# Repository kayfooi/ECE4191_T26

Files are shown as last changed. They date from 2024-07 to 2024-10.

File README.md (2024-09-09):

# ECE4191_T26

### World Coordinate System

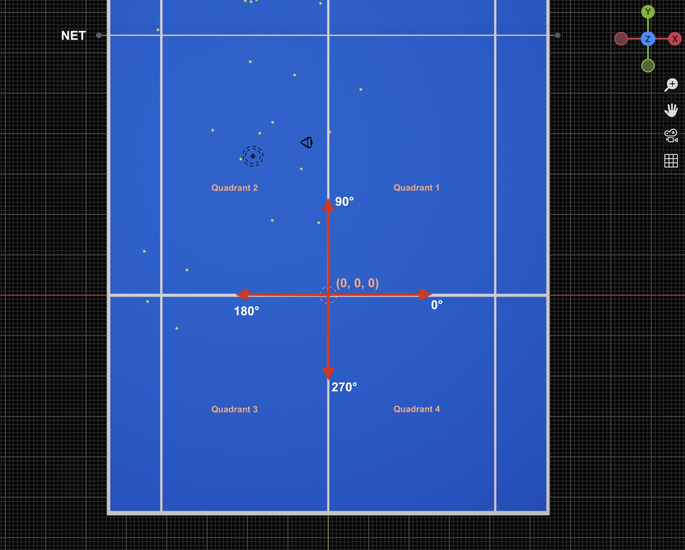
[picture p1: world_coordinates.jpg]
world coordinates


### Libraries
#### pigpio
- needs to be started, terminal command: 
```
sudo pigpiod
```
- python library that handles GPIO on a low-level
- Can produce hardware-timed PWM signals on any GPIO
- Known issue: encoder counts pause rarely and have to restart pigpio in terminal
```
sudo killall pigpiod
sudo pigpiod
```

#### ultralytics
- Loads YOLO model
- Seems quite slow so may be worth investigating other options

### Code Overview

#### [main](main.py)
High level main file to handle ALL logic relevant to the final competion

#### [camera](camera.py)
Object to handle all things computer vision including camera settings/capturing, detection algorithms and coordinate transforms

#### [robot](robot.py)
Object that implements instructions given to the robot (note that all *competition logic* should be kept in main)

#### [world](world.py)
Object that represents current state of the world. Includes tennis court dimensions, starting poses, tennnis balls etc.

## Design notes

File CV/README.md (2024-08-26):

## COMPUTER VISION NOTES

#### Calibration
- [camera_calibrate.py](camera_calibrate.py) calculates a homography matrix that transforms image coordinates into real-world coordinates (relative to a camera positioned at (0, 0, 0))
  - takes [calibration_img.png](calibration_img.png) and [calibration.csv](calibration.csv) as input
  - plots a lot of stuff
  - [calibration.csv](calibration.csv) is currently created manually (we should only need to do this a single time once the robot is constructed and the camera is in a fixed position relative to the ground)

#### Distortion
- Minor barrel distortion appears present
- No major effect on homography accuracy, especially for pixels in the centre of the image
- Attempted to use [checkerboard](./checkerboard/) images to [correct distortion with OpenCV](https://learnopencv.com/camera-calibration-using-opencv/) with minimal success

#### Object Identification
- Will probably use a combination of colour masking, edge detection, maybe k-means clustering?

#### Test case generation
- Blender used to generate many images to test the performance of various CV algorithms 
- Simulates barrel distortion from camera
- Various lighting / shadow conditions
- Various amouts of noise / motion blur

#### Testing
- Put all images in a test set in a single folder
- If you want to automatically test accuracy, create a cases.json file with the structure:
- [
    {
      "caseID": str,
      "cam_heading": int,
      "cam_location": [x,y,z],
      "balls": [{
          "ball_id": str,
          "world": [x,y,z],
          "image": [u,v],
          "in_bounds": bool
      }]
    }
  ]
- *^^ [image_labeller.py](test_imgs/image_labeller.py) can do this for you*
- Import ball detections algorithms in [test_cv.py](test_cv.py)
- Run test_cv (make sure you are in CV folder)

#### TODO
- [x] Geometry
- [ ] Tennis ball identification
- [x] Test case generation

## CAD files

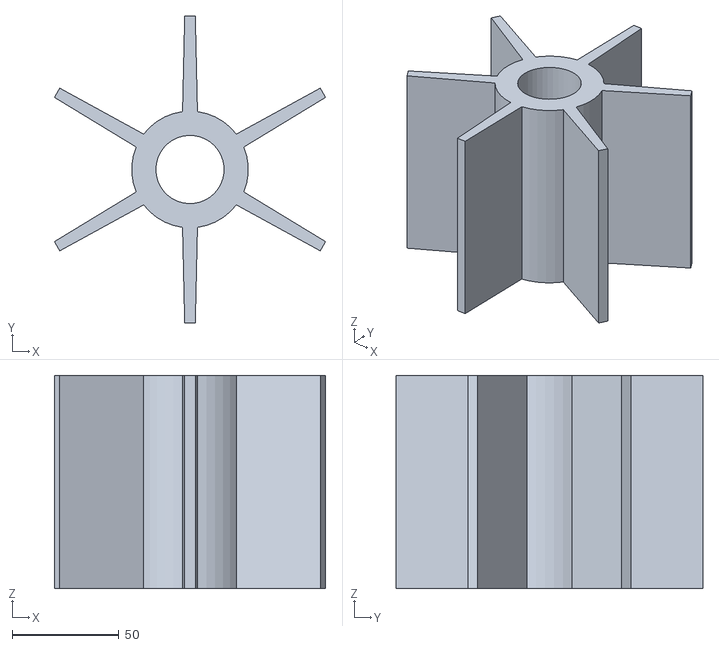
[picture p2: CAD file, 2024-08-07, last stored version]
Initial SW Paddle Designs/6SpokeDesignBigHoleEdition.STL
127.2 x 144.0 x 100.0

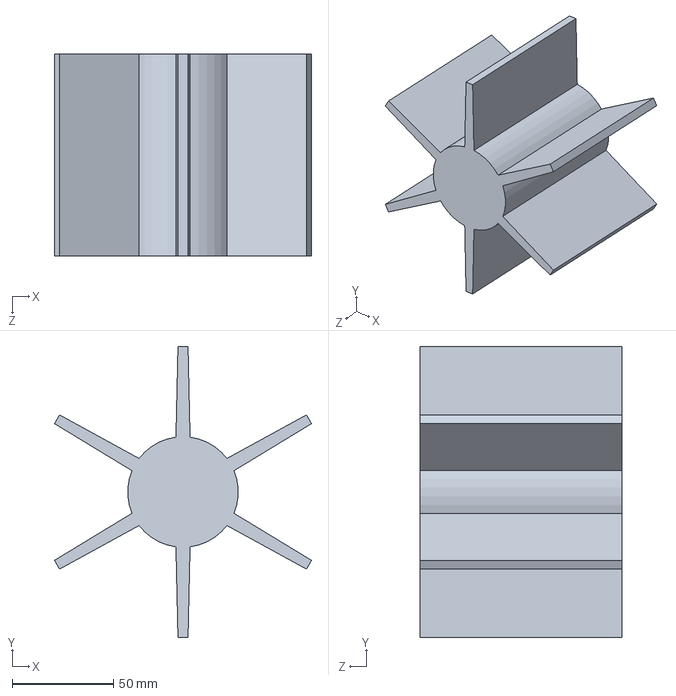
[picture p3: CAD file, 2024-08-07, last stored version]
Initial SW Paddle Designs/6SpokeDesign.SLDPRT
127.2 x 144.0 x 100.0 mm

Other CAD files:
Initial SW Paddle Designs/6SpokeDesign.STL

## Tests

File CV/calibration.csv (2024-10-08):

Image X (px) | Image Y (px) | World X (m) | World Y (m)
83 | 273 | 0.6 | 0.3
56 | 137 | 1.2 | 0.6
136 | 85 | 1.8 | 0.6
177 | 59 | 2.4 | 0.6
315 | 32 | 3.6 | 0
455 | 62 | 2.4 | -0.6
497 | 91 | 1.8 | -0.6
577 | 142 | 1.2 | -0.6
551 | 278 | 0.6 | -0.3
321 | 274 | 0.6 | 0
317 | 139 | 1.2 | 0
316 | 88 | 1.8 | 0
316 | 62 | 2.4 | 0

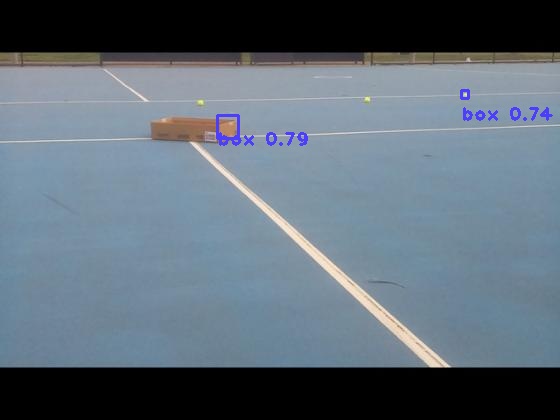
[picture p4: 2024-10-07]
YOLO_result.jpg

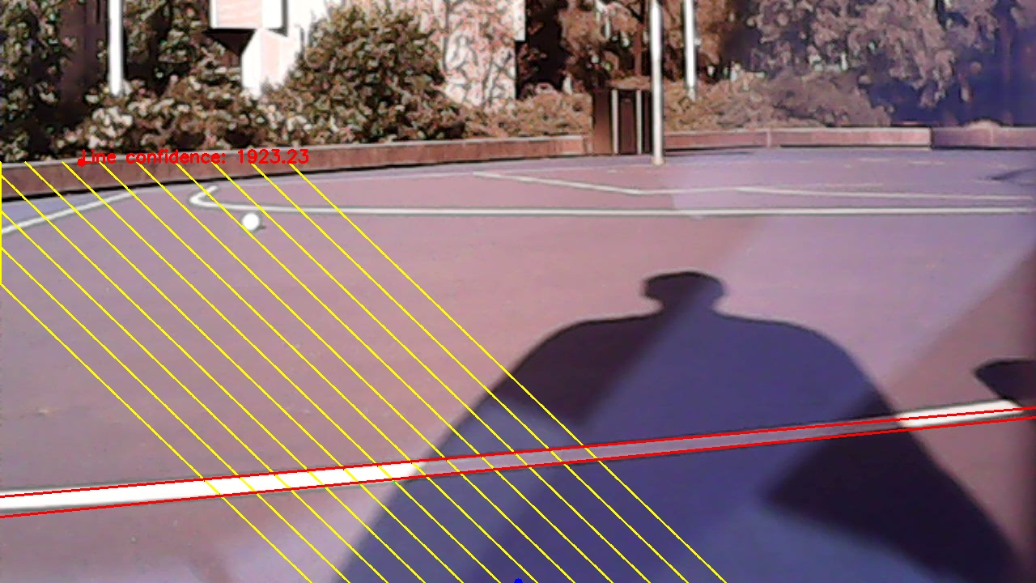
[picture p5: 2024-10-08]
test_results/1728356265/line_detect_192_100_200.jpg

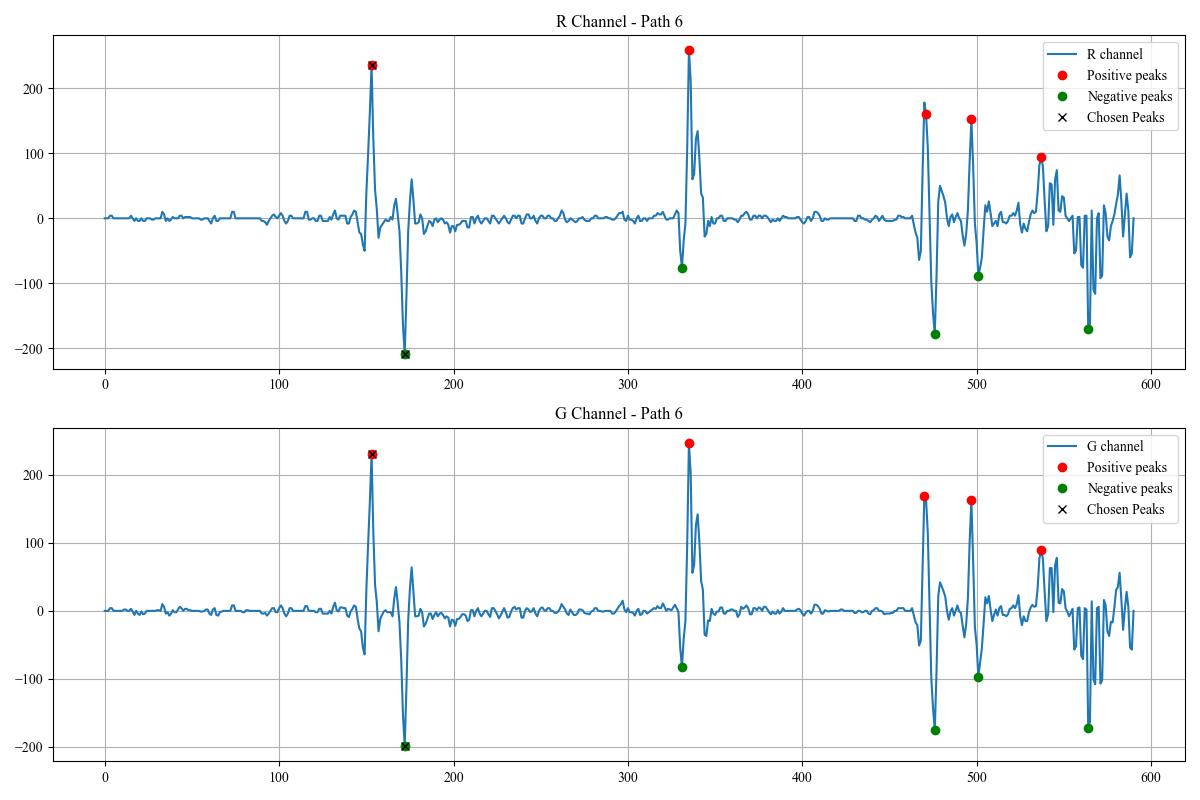
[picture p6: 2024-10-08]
test_results/1728356265/line_detect_192_800_150_peaks.jpg

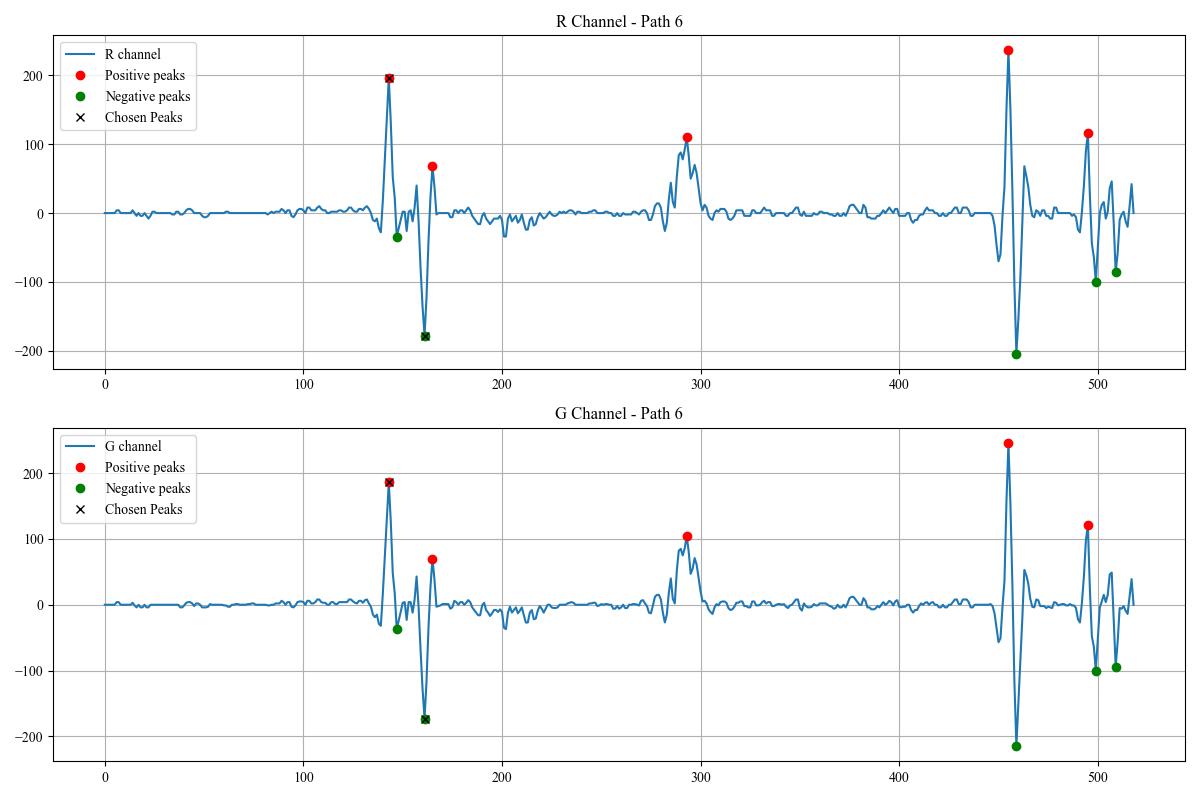
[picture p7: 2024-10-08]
test_results/1728355701/line_detect_192_640_200_peaks.jpg

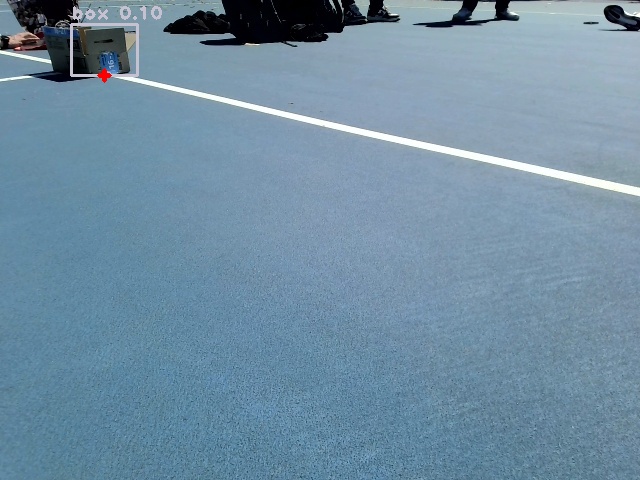
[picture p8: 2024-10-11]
test_results/1728508676/box_detect_result_0.jpg

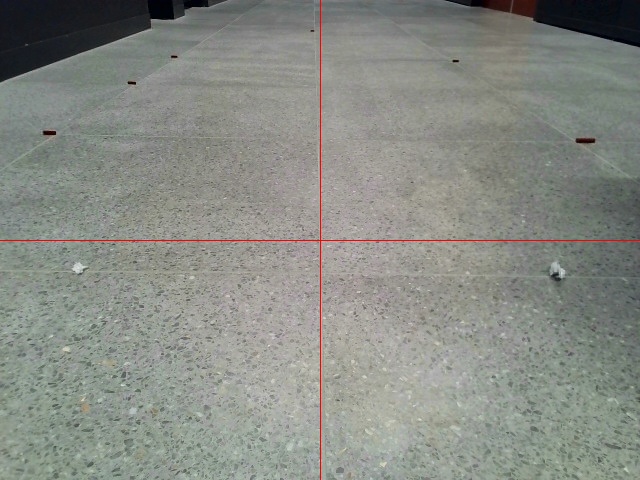
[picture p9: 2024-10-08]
CV/calibration_img.jpg

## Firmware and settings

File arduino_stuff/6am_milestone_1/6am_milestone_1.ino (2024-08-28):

// define constants
#define PI 3.1415926535897932384626433832795

void decodeSerial(String serialInput);

// define speed and direction pins for motors
// Might need PWM pins for speed
// Pins 2-13 and 44-46
// NAME THESE MOTORS LEFT AND RIGHT EVENTUALLY
int motorRightA = 35;
int motorRightB = 34;
int motorLeftA = 37;
int motorLeftB = 36;

// define encoder pins for motors
// Interrupt pins are 2-3 and 18-21
int encoderRight = 3;
int encoderRightin = 18;
int encoderLeft = 2;
int encoderLeftin = 19;

// define variables for encoder counts
volatile long encoderRightCount = 0;
volatile long encoderLeftCount = 0;
// test shit
volatile long encoderRightCount2 = 0;
volatile long encoderLeftCount2 = 0;

// define variables for position and pose
volatile long xPos = 0;
volatile long yPos = 0;
volatile long thPos = 0;

// time between pings
const unsigned long u_wait = 50; //ultrasonic

// memory variables
unsigned long u_Cms; //ultrasonic current
unsigned long u_Pms; //ultrasonic previous

unsigned long current_t;
unsigned long end_t;


// define variables for PID control
long previousTime = 0;
float ePrevious = 0;
float eIntegral = 0;

String serialInput;
  String testSerialMessage = "R_45";
  String testSerialMessage2 = "R_315";

void setup() {
  // put your setup code here, to run once:
  Serial.begin(9600);
  Serial2.begin(9600);

  Serial.println("serial test");
  pinMode(motorRightA, OUTPUT);
  pinMode(motorRightB, OUTPUT);
  pinMode(motorLeftA, OUTPUT);
  pinMode(motorLeftB, OUTPUT);
  
  pinMode(encoderRight, INPUT);
  pinMode(encoderRightin, INPUT);
  pinMode(encoderLeft, INPUT);
  pinMode(encoderLeftin, INPUT);

  // Interrupts
  attachInterrupt(digitalPinToInterrupt(encoderRight), handleEncoder1, RISING);
  attachInterrupt(digitalPinToInterrupt(encoderLeft), handleEncoder2, RISING);
  // test shit
  attachInterrupt(digitalPinToInterrupt(encoderRightin), handleEncoder11, RISING);
  attachInterrupt(digitalPinToInterrupt(encoderLeftin), handleEncoder22, RISING);

}

// void loop() {
// //  // put your main code here, to run repeatedly:

// //          Test when connected to RPI
// //  if (Serial.available() > 0 ) {
// //    String input = Serial.readStringUntil('\n')
// //  }
//   // String testSerialMessage = "T_-200";
//   // decodeSerial(testSerialMessage);
//   // delay(10000);
//   delay(1000);
//   AngleToRotate(90, -1);
//   delay(100);
//   DistanceToStraight(1000, 1);
//   delay(10000);
//   /*
//   AngleToRotate(10, -1);
//   AngleToRotate(10, -1);
//   AngleToRotate(10, -1);
//   AngleToRotate(10, -1);
//   AngleToRotate(10, -1);
//   AngleToRotate(10, -1);
//   AngleToRotate(10, -1);
//   AngleToRotate(10, -1);
//   */

// }



void loop() {
  delay(20);
  while (Serial2.available() > 0 ) {
     String input = Serial2.readStringUntil('\n');
     input.trim();
     Serial.println("recieved");
     Serial.println(input);
    decodeSerial(input);
  }
  delay(20);

  // delay(1000);
  // AngleToRotate(90, -1);
  // delay(100);
  // DistanceToStraight(1000, 1);
  // delay(10000);

  // delay(20);

  // AngleToRotate(45,1);
  // delay(500);
  // encoderRightCount = 0;
  // encoderLeftCount = 0;

  // delay(1000);

  // AngleToRotate(45,-1);
  // encoderRightCount = 0;
  // encoderLeftCount = 0;

  // delay(1000);

  // //go straight
  // delay(2000);
  // //straight
  // digitalWrite(motorRightA, LOW);
  // digitalWrite(motorRightB, HIGH);
  // digitalWrite(motorLeftA, LOW);
  // digitalWrite(motorLeftB, HIGH);
  // delay(3700); //3000
  // digitalWrite(motorRightA, LOW);
  // digitalWrite(motorRightB, LOW);
  // digitalWrite(motorLeftA, LOW);
  // digitalWrite(motorLeftB, LOW);
  // delay(1200);

//  String testSerialMessage = "T_-20";
//  decodeSerial(testSerialMessage);
//  delay(10000);
  // delay(1000);
  // DistanceToStraight(500,1);
  // delay(5000);
  // DistanceToStraight(1000,1);
  // delay(1000);
  // DistanceToStraight(500,-1);
  // delay(1000);
  // DistanceToStraight(1000,-1);
  // delay(100000);
  // delay(500);
  // decodeSerial(testSerialMessage);
  // delay(1000);
  // decodeSerial(testSerialMessage2);
  // delay(1000);

}

// Functions called during interrupts

void handleEncoder1() {
  encoderRightCount++;
}
void handleEncoder2() {
  encoderLeftCount++;
}
// test shit
void handleEncoder11() {
  encoderRightCount2++;
}
void handleEncoder22() {
  encoderLeftCount2++;
}



void moveMotor(int dirPin, int pwmPin, float u) {
  // Maximum motor speed
  float speed = fabs(u);
  if (speed > 255) {
    speed = 255;
  }
  // Stop the motor during overshoot
  if (encoderLeftCount > encoderRightCount) {
    speed = 0;
  }
  // Control the motor
  int direction = 1; // direction set to 1 because right motor mounted in reverse
  digitalWrite(dirPin, direction);
  analogWrite(pwmPin, speed);
}

float pidController(int target, float kp, float kd, float ki) {
  // Measure the time elapsed since the last iteration
  long currentTime = micros();
  float deltaT = ((float)(currentTime - previousTime))/1.0e6;

  // Compute the error, derivative and integral
  int e = encoderLeftCount - target;
  float eDerivative = (e - ePrevious)/deltaT;
  eIntegral = eIntegral + e*deltaT;

  // Compute the PID control signal
  float u = (kp*e) + (kd*eDerivative) + (ki*eIntegral);

  // Update variables for the next iteration
  previousTime = currentTime;
  ePrevious = e;

  return u;
}


// Distance to encoder count translation function (helper function)
int DistanceToEncoderCount(float distance) { 
  // Serial.println("in disttoencoder");

  // define number of encoder counts per rotation
  int constant_count = 900;
  // define wheel diameter
  int diameter = 54; // [mm]
  // distance travelled by wheel in one rotation
  float dist_per_rotation = diameter*PI;  // [m*1000] = [mm]
  // distance travelled per encoder count
  float dist_per_count = dist_per_rotation/constant_count;
  // Serial.println(diameter);
  // encoder counts required to travel specified distance
  float encoder_counts_req = distance/dist_per_count;

  return round(encoder_counts_req);

}

float EncodertoDist(int Encoder)
{
  // define number of encoder counts per rotation
  int constant_count = 900;
  // define wheel diameter
  int diameter = 54; // [mm]
  // distance travelled by wheel in one rotation
  float dist_per_rotation = diameter*PI;  // [m*1000] = [mm]
  // distance travelled per encoder count
  float dist_per_count = dist_per_rotation/constant_count;

  float distance = Encoder * dist_per_count;
  return distance;
}

float EncodertoAngle(int Encoder)
{
  float angle = Encoder/9.3;
  return angle;
}

// Function to convert angle input to encoder value
int AngletoEncoder(float Angle) {
  int Encoder = round((Angle/360)*3340);
  return Encoder;
}

void updatePosition(float dist)
{
  xPos = xPos + dist*cos(thPos*PI/180);
  yPos = yPos + dist*sin(thPos*PI/180);
  Serial.print("x: ");
  Serial.print(xPos/1000);
  Serial.println(" m");
  Serial.print("y: ");
  Serial.print(yPos/1000);
  Serial.println(" m");
 
}

void updatePose(float angle)
{
  thPos = thPos + angle;
  Serial.print("Current Pose: ");
  Serial.print(thPos);
  Serial.println(" degrees");
}

// Straight line movement function
void MoveStraight(int direction) {
  
  // set motor rotation direction
  // 1 indicates forward, -1 indicates reverse, 0 indicates stop
  // 2 indicates Right Forward, 3 indicates Left Forward
  // -2 indicates Right Backward, -3 indicates Left Backward
  if (direction == 1) {
    digitalWrite(motorRightA, LOW);
    digitalWrite(motorRightB, HIGH);
    digitalWrite(motorLeftA, LOW);
    digitalWrite(motorLeftB, HIGH);
  }
  if (direction == -1) {
    digitalWrite(motorRightA, HIGH);
    digitalWrite(motorRightB, LOW);
    digitalWrite(motorLeftA, HIGH);
    digitalWrite(motorLeftB, LOW);
  }
   if (direction == 0) {
    digitalWrite(motorRightA, LOW);
    digitalWrite(motorRightB, LOW);
    digitalWrite(motorLeftA, LOW);
    digitalWrite(motorLeftB, LOW);
  }
    if (direction == 2) {
    digitalWrite(motorRightA, LOW);
    digitalWrite(motorRightB, HIGH);
  }
      if (direction == 3) {
    digitalWrite(motorLeftA, LOW);
    digitalWrite(motorLeftB, HIGH);
  }

      if (direction == -2) {
    digitalWrite(motorRightA, HIGH);
    digitalWrite(motorRightB, LOW);
  }
  
      if (direction == -3) {
    digitalWrite(motorLeftA, HIGH);
    digitalWrite(motorLeftB, LOW);
  }


}

void MoveRotate(int direction) {

  // direction = 1 = clockwise, direction = -1 = anticlockwise
  if (direction == 1) {
    digitalWrite(motorRightA, HIGH);
    digitalWrite(motorRightB, LOW);
    digitalWrite(motorLeftA, LOW);
    digitalWrite(motorLeftB, HIGH);
  }
  if (direction == -1) {
    digitalWrite(motorRightA, LOW);
    digitalWrite(motorRightB, HIGH);
    digitalWrite(motorLeftA, HIGH);
    digitalWrite(motorLeftB, LOW);
  }
}

void DistanceToStraight(int distance, int direction) {

  // Function converts distance input into motor movement
  int encoderCountsToDist = DistanceToEncoderCount(distance);
  // Serial.println("entered correct if statement");
  //  Serial.println(encoderCountsToDist);
  //  Serial.println(distance);

  current_t = millis();

  if(direction == 1){
    
     while(encoderLeftCount < encoderCountsToDist){
      MoveStraight(1);
      // Serial.print("Count: ");
      // Serial.println(encoderLeftCount);
      end_t = floor(distance*(3.7));
      if (current_t + (distance/1000)*3600 <= end_t) {
        current_t = 0;
        end_t = 0;
        break;
      }
     }
  }
  if(direction == -1){
    
     while(encoderLeftCount < encoderCountsToDist){
      MoveStraight(-1);
      // Serial.print("Count: ");
      // Serial.println(encoderLeftCount);
      end_t = floor(distance*(3.7));
      if (current_t + (distance/1000)*3600 <= end_t) {
        current_t = 0;
        end_t = 0;
        break;
      }
     }
  }     
   MoveStraight(0);
   delay(1000);
   float dist = EncodertoDist(encoderLeftCount);  
   updatePosition(dist);
   encoderLeftCount = 0; 
  //   return;
}


void AngleToRotate(int angle, int direction) { // direction = 1 = clockwise, direction = -1 = anticlockwise
  // Function converts input angle into motor movement
  // effectively reset current encoder count
  //encoderLeftCount2 = 0;
  //encoderLeftCount = 0;
  int encodeReq = AngletoEncoder(angle);
  // Serial.print("required encoder: ");
  //  Serial.println(encodeReq);
  //  Serial.println(encoderLeftCount);
  if (direction == 1) {
    //MoveRotate(1);
    current_t = millis();
    

    while (encoderRightCount < encodeReq) {
      
      MoveStraight(3);
      MoveStraight(-2);
      Serial.print("Encoder: ");
       Serial.println(encoderLeftCount);
      //  end_t = millis();
      end_t = angle*(90/650);
       Serial.println("while test");
       Serial.println(current_t);
       Serial.println(end_t);
       if (current_t + (angle/360)*2600 <= end_t) {
         current_t = 0;
         end_t = 0;
         break;
       }
    }
    Serial.println("out of loop");
    MoveStraight(0);
    delay(1200);
  }
  if (direction == -1) {
    //MoveRotate(-1);
    current_t = millis();
    while (encoderLeftCount < encodeReq) {
      
      // Serial.print("Encoder: ");
      // Serial.println(encoderLeftCount);
      MoveStraight(-3);
      MoveStraight(2);
      end_t = millis();
      if (current_t + (angle/360)*2600 <= end_t) {
        current_t = 0;
        end_t = 0;
        break;
      }
    }
    MoveStraight(0);
  }
  MoveStraight(0);
  delay(1000);
  float angleRot = EncodertoAngle(encoderLeftCount);  
  updatePose(angleRot);
  encoderLeftCount = 0;
  /*
  //    if (encoderLeftCount >= 200*angle){
    MoveStraight(0);
    Serial.println(encoderLeftCount);
    delay(1000);
    float angle = EncodertoAngle(encoderLeftCount);
    updatePose(angle * direction);
    encoderLeftCount = 0;
  //    return;
  //    }  
  }
  if (direction == -1) {
    while (encoderLeftCount < 200*angle){
      MoveStraight(-3);
      MoveStraight(2);
      //Serial.println(encoderLeftCount);
    }
  
  //    if (encoderLeftCount >= 200*angle){
    MoveStraight(0);
    Serial.println(encoderLeftCount);
    delay(1000);
    float angle = EncodertoAngle(encoderLeftCount);
    updatePose(angle * direction);
    encoderLeftCount = 0;
  //    return;
  //    }

  */
}



void decodeSerial(String serialInput){
  int distance_angle = serialInput.substring(2).toInt();
//  Serial.println(serialInput);
//  Serial.println(distance_angle);
//  Serial.println(serialInput.charAt(0));
  if(serialInput.charAt(0) == 'R'){ // Rotational input
    if(distance_angle < 0){
      AngleToRotate(360 - abs(distance_angle), 1); //changed to turn right but to right angle
    }
    else if(distance_angle > 0){
      AngleToRotate(abs(distance_angle), 1);
    }
  }
  if(serialInput.charAt(0) == 'T'){ // Translate / Straight line input 
//    Serial.println("entered translate");
    if(distance_angle < 0){
      DistanceToStraight(abs(distance_angle), -1);
//      Serial.println("entered correct if statement");
    }
    else if(distance_angle > 0){
      DistanceToStraight(abs(distance_angle), 1);
    }    
  }
}


// //GPT version
// void decodeSerial(String serialInput) {
//     // Split the serial input into individual commands
//     int startIndex = 0;
//     int endIndex = serialInput.indexOf('_', startIndex);

//     while (endIndex != -1) {
//         // Extract the command part
//         String command = serialInput.substring(startIndex, endIndex + 1);
//         int distance_angle = command.substring(2).toInt();

//         // Process the command
//         if (command.charAt(0) == 'R') { // Rotational input
//             if (distance_angle < 0) {
//                 AngleToRotate(abs(distance_angle), -1);
//             } else if (distance_angle > 0) {
//                 AngleToRotate(abs(distance_angle), 1);
//             }
//         } else if (command.charAt(0) == 'T') { // Translate / Straight line input
//             if (distance_angle < 0) {
//                 DistanceToStraight(abs(distance_angle), -1);
//             } else if (distance_angle > 0) {
//                 DistanceToStraight(abs(distance_angle), 1);
//             }
//         }

//         // Move to the next command
//         startIndex = endIndex + 1;
//         endIndex = serialInput.indexOf('_', startIndex);
//     }
// }


/*
// functions for ultrasonic

void ReadCm() {
  u_Cms = millis();
  if (u_Cms > u_Pms + u_wait) {

  
  // Clears trigger pins
  for (uint8_t j = 0; j < SONAR_NUM; j++){
    digitalWrite(trigPins[j], LOW);
  }
  delayMicroseconds(2);

  // Gets distance from sensors
  int d_left = (sonar[0].ping_cm())*10;
  int d_mid = (sonar[1].ping_cm())*10;
  int d_right = (sonar[2].ping_cm())*10;

  u_Pms = u_Cms;
  }
}
*/

// 1 - rotate until ball found
void rotateUntilBallFound(){
  // read all 3 sensors
  
  // if ball detected in side sensor, rotate until middle sensor is closest to ball
  // call function 2 
}
// 2 - go forward until ball is within certain distance
// 3 - make correctional movements to ensure ball is closest to middle sensor

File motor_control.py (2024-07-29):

import time
import RPi.GPIO as GPIO

# Assign pins to GPIOs (For demo only, different GPIOs can be used in practice)
motor_A_in1 = 18
motor_A_in2 = 23
motor_A_en = 13

motor_B_in2 = 24
motor_B_in1 = 25
motor_B_en = 19

# Set GPIO modes
GPIO.setmode(GPIO.BCM)
GPIO.setup(motor_A_in1, GPIO.OUT)
GPIO.setup(motor_A_in2, GPIO.OUT)
GPIO.setup(motor_B_in1, GPIO.OUT)
GPIO.setup(motor_B_in2, GPIO.OUT)
GPIO.setup(motor_A_en, GPIO.OUT)
GPIO.setup(motor_B_en, GPIO.OUT)

## Motor Direction Control
start_time = time.time()

# Rotate both motor L and R anticlockwise for 3 seconds
while time.time() - start_time < 3:
    GPIO.output(motor_A_en, GPIO.HIGH)
    GPIO.output(motor_B_en, GPIO.HIGH)

    GPIO.output(motor_A_in1, GPIO.LOW)
    GPIO.output(motor_A_in2, GPIO.HIGH)

    GPIO.output(motor_B_in1, GPIO.LOW)
    GPIO.output(motor_B_in2, GPIO.HIGH)

GPIO.cleanup()


## Motor Speed Control w/ PWM

# Create PWM instance with a frequency of 100 Hz
pwm_L = GPIO.PWM(motor_A_en, 100)
pwm_R = GPIO.PWM(motor_B_en, 100)

# Start PWM with a duty cycle of 0%
pwm_L.start(0)
pwm_R.start(0)

# Change PWM duty cycle to 20%
pwm_L.ChangeDutyCycle(20)
pwm_R.ChangeDutyCycle(20)

start_time = time.time()

# Rotate both motor L and R anticlockwise for 3 seconds with 20% of the full motor speed
while time.time() - start_time < 3:
    GPIO.output(motor_A_in1, GPIO.LOW)
    GPIO.output(motor_A_in2, GPIO.HIGH)

    GPIO.output(motor_B_in1, GPIO.LOW)
    GPIO.output(motor_B_in2, GPIO.HIGH)

pwm_L.stop()
pwm_R.stop()
GPIO.cleanup()

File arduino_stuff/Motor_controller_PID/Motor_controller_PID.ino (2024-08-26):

// Define pin numbers for motors
#define DIR1 4
#define PWM1 5
#define DIR2 7
#define PWM2 6

// Define pin numbers for encoders
#define encoder1Pin 44
#define encoder2Pin 3

// Variables for encoder counts
volatile long encoder1Count = 0;
volatile long encoder2Count = 0;

// Variables for PID control
long previousTime = 0;
float ePrevious = 0;
float eIntegral = 0;

void setup() {
  
  Serial.begin(9600);

  // Set pin modes
  pinMode(DIR1, OUTPUT);
  pinMode(PWM1, OUTPUT);
  pinMode(DIR2, OUTPUT);
  pinMode(PWM2, OUTPUT);
  pinMode(encoder1Pin, OUTPUT);
  pinMode(encoder2Pin, OUTPUT);

  // Interrupts
  attachInterrupt(digitalPinToInterrupt(encoder1Pin), handleEncoder1, RISING);
  attachInterrupt(digitalPinToInterrupt(encoder2Pin), handleEncoder2, RISING);

}

void loop() {
  // Set desired setpoint for motor 2
  int target = encoder1Count;

  // Move motor 1
  digitalWrite(DIR1, 1);
  analogWrite(PWM1, 50);
  
  // PID gains and computation
  float kp = 2.0;
  float kd = 0.0;
  float ki = 0.0;
  float u = pidController(target, kp, kd, ki);

  // Control motor 2 based on PID
  moveMotor(DIR2, PWM2, u);

  // Print statements for debugging
  Serial.print(encoder1Count);
  Serial.print(", ");
  Serial.println(encoder2Count);

}

// Functions called during interrupts

void handleEncoder1() {
  encoder1Count++;
}
void handleEncoder2() {
  encoder2Count++;
}

void moveMotor(int dirPin, int pwmPin, float u) {
  // Maximum motor speed
  float speed = fabs(u);
  if (speed > 255) {
    speed = 255;
  }
  // Stop the motor during overshoot
  if (encoder2Count > encoder1Count) {
    speed = 0;
  }
  // Control the motor
  int direction = 0;
  digitalWrite(dirPin, direction);
  analogWrite(pwmPin, speed);
}

float pidController(int target, float kp, float kd, float ki) {
  // Measure the time elapsed since the last iteration
  long currentTime = micros();
  float deltaT = ((float)(currentTime - previousTime))/1.0e6;

  // Compute the error, derivative and integral
  int e = encoder2Count - target;
  float eDerivative = (e - ePrevious)/deltaT;
  eIntegral = eIntegral + e*deltaT;

  // Compute the PID control signal
  float u = (kp*e) + (kd*eDerivative) + (ki*eIntegral);

  // Update variables for the next iteration
  previousTime = currentTime;
  ePrevious = e;

  return u;
}

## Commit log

2024-07-29 Create motor_control.py
    L298N H-Bridge IC code to control motor direction / speed
2024-08-07 SolidWorks Models
    [6SpokeDesign.SLDPRT]
2024-08-08 Created motor_library.py
    motor control via libraries
2024-08-08 added motor select
2024-08-12 Computer Vision Updates
    - Added folder and README (just for CV)
    - Wrote code to find homography that maps image coords to x, y world coords
    - Experimented with fixing barrel distortion (no success)
    [calibration.csv]
2024-08-14 added basic encoder stuff
2024-08-14 Adding test case variants
    - Darkness, overexposure, shadows and motion blur
    - All have similar lens distorition to our camera
2024-08-14 created arduino stuff
2024-08-14 updated ultrasonic + colour sensor code
2024-08-14 updated ultrasonic sensor
2024-08-14 Create ultrasonic_sensor.md.txt
    ultrasonic sensor stuff by Izzy
2024-08-15 Completed first iteration of high-level milestone 1 algorithm
    - Purely vision based for now
    - Simplified robot.py to contain very high level instructions. I am assuming all the kinimatic control will be handled on the Arduino cause it has access to the encoders
2024-08-21 Serial communication from Arduino to RPi (not tested)
2024-08-22 Adding real-life test images
    [yolov3-tiny.cfg]
2024-08-25 Adding YOLOv8 models
    - Two YOLOv8 nano models trained on our data
    - 'YOLOv1' is trained on 150 real test images
    - 'YOLOv2' is trained on ~1500 generated test images + 150 real test images
    - Both performing pretty well, can play around with conf parameter in camera.py
2024-08-27 Update ECE4191_dual_motor_test.ino
    changed pinouts to reflect redone wiring + implemented functions for rotation + tidied up some of the code
2024-08-27 Update ECE4191_dual_motor_test.ino
    Changes to incorporate serial comms with raspberry pi - not tested yet
2024-08-27 Update ECE4191_dual_motor_test.ino
    more changes, the distance to encoder count wasnt working, think the units were too small and we were dropping values, works now with mm units
    [ECE4191_dual_motor_test.ino]
2024-08-27 movement & sensor alg written
2024-08-28 Calibrated good camera and tested
    [calibration.csv]
2024-08-28 Update ECE4191_dual_motor_test.ino
    fixed rotation and motion
    [ECE4191_dual_motor_test.ino]
2024-08-28 Update ECE4191_dual_motor_test.ino
    hide print statement for clarity
2024-08-28 Update ECE4191_dual_motor_test.ino
    fix odometry cpde
    [ECE4191_dual_motor_test.ino]
2024-08-28 Update ECE4191_dual_motor_test.ino
    update print statement to get position clarity
2024-08-28 Update ECE4191_dual_motor_test.ino
    daisy chaining movement
2024-08-28 Revert "send x y coords"
    This reverts commit 09254423020cf24bed799068c43128101978ecab.
    [ECE4191_dual_motor_test.ino, milestone1.py, robot.py]
2024-08-28 Revert "Merge branch 'main' of https://github.com/kayfooi/ECE4191_T26 into main"
    This reverts commit dabbae28072754ad4306fd81a69a7df90d5b5947, reversing
    changes made to d0641b298e2e3e54461d1efe29da4f19a1a3e665.
    [ECE4191_dual_motor_test.ino]
2024-08-28 Serial comms with arduino
2024-08-28 added arduino milestone code
2024-08-28 added 6am edition of arduino code
2024-08-28 Update 6am_milestone_1.ino
    change to serial code due to borked pin
2024-09-05 created laser.py with laser functions to use in main
2024-09-05 updated laser.py
    added in comments how to implement laser functions
2024-09-05 PID Motor Control
2024-09-07 Tuning motor parameters
    - Calibrated meter/degrees -> encoder count conversion
    - Adjust overshoot with speed
    - Works well at speeds around 0.1-0.5 m/s or 20-50 degrees/second
    [WheelMotor.py]
2024-09-10 updated infrared.py
    used pigpio library for IR sensors
2024-09-10 updated infrared & sensortest
    added a test file to run both sensors on thursday & added functions to infrared sensor
2024-09-11 created servo.py
    with all servo code for the mg90s
2024-09-12 Motor testing on Pi Zero 2
2024-09-18 importing laser code
2024-09-19 Adding lighter YOLO model
    [model.ncnn.param]
2024-09-23 Motor Improvements
    - Motor stops with IR Sensor on GPIO5
    - Better test cases
    - Encoders became inaccurate at higher speeds
2024-09-23 Adjusting Camera Settings
    - Able to manually set brightness
    - Updated YOLO model so it doesn't have big load time
    - Inference is around ~800ms (with camera capture)
    [camera.py]
2024-09-27 Servo work
2024-09-27 Testing delivered servos
2024-10-01 Line Detection + New YOLO Training - main line detection alg in test_line_detection - new model detects balls, cardboard box and legs (not fully tested yet)
    [model.ncnn.param]
2024-10-03 Testing servo
2024-10-05 Tuning Motor parameters
2024-10-06 updated with laser stuff
    in robot.py for testing and in wheelmotor for interrupt
2024-10-06 added stuff for reversepark sensor
    [WheelMotor.py]
2024-10-07 New YOLO Model + integrating line detection
    [model.ncnn.param]
2024-10-07 Adding tool for calibration
2024-10-08 Updated homography
    [calibration.csv]
